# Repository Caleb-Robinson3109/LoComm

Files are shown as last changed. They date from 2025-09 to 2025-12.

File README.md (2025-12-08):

# LoComm Devices: Secure P2P Communication
*LoComm Devices are ESP32s with a LoRa module. The devices provides a low power solution for the secure transmission of data over 915 MHz radio. Providing long range but lower bandwidth. With the use of the computer API applications can be built to utilize the device’s functionality*

## Team Members
Ethan Kleine - ejkmvp@umsystem.edu \
Abraham Yirga - aayfn7@umsystem.edu \
Caleb Robinson - cmrd2d@umsystem.edu \
Kush Solanki - kysp2d@umsystem.edu \
Shaun Wolfe - swgw8@umsystem.edu \
Arjun Kirubakaran - apkccy@umsystem.edu

## Problem Statement
In areas without reliable internet or cellular infrastructure, people, and IoT devices may face serious communication barriers. In these areas secure communication is still required, protecting sensitive or proprietary information. A low cost device that provides secure communication, where wireless infrastructure is not available is a need for these situations.

## Solution
This project provides a secure peer to peer communication system that operates without internet or cellular infrastructure. Using LoRa enabled ESP32 devices and a desktop application, users can exchange secure text messages, giving people a way to communicate privately and consistently. 

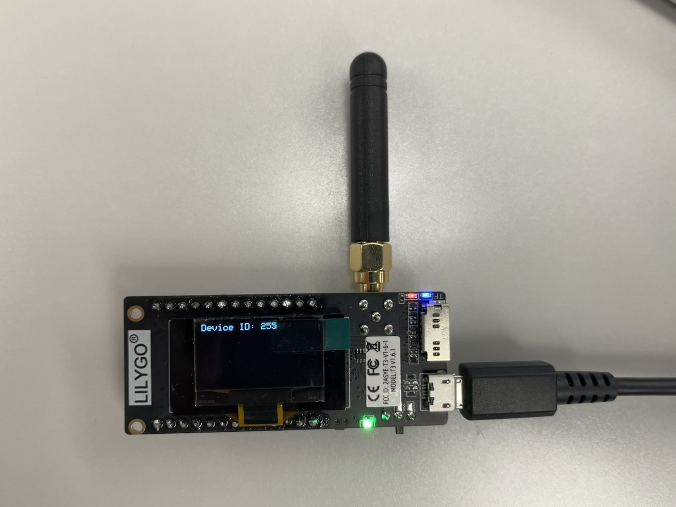
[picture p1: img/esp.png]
ESP32 with LoRa Module


LILYGO LoRa32 915Mhz ESP32 Development Board OLED 0.96 Inch SD Card BLE WiFi \
Cost: $30.00

## Device Security
The LoComm device is designed to maintain security in any remote environment regardless of available infrastructure.
- **Authentication** - Access to each LoComm device requires a user-set password.
- **Authorization** - The user-set password is required to determine the shared symmetric key used for encryption. 
- **Confidentiality** - Shared secret key encryption via AES-GCM
- **Integrity** - Shared secret key encryption via AES-GCM. Replay attacks are avoided with timestamped messages.
- **Reliability** - Message ACKs are used to verify messages were received, and messages are segmented to aid transmission success rate.

## Message Format
| Feild Name | Field Size |
| --- | :---: |
| Start Byte | 1 Byte |
| 0 | 1 Byte |
| Sender ID (Encrypted) | 1 Byte |
| Receiver ID (Encrypted) | 1 Byte |
| Message Number (Encrypted) | 2 Bytes |
| Sequence Number (Encrypted) | 1 Byte |
| Sequence Count (Encrypted) | 1 Byte |
| Timestamp (Encrypted) | 4 Bytes |
| DATA (Encrypted) | N Bytes |
| Encryption Overhead (Encrypted) | 20 Bytes |
| CRC | 2 Bytes |
| End Byte | 1 Byte |

## Device API
The API consists of many functions to communicate with the device in Python.  These API functions can facilitate the connection form application to device, transmission of messages, pairing key handling, etc. 

## Desktop App
The desktop application is designed to be interactive and support secure peer to peer messaging over short range connections.

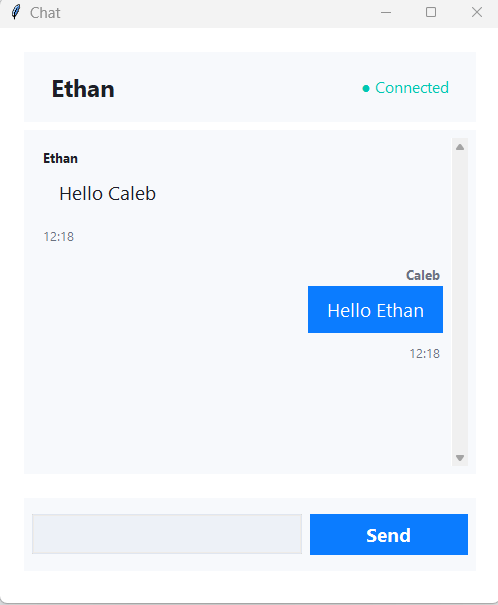
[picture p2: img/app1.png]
Desktop App Chat Page

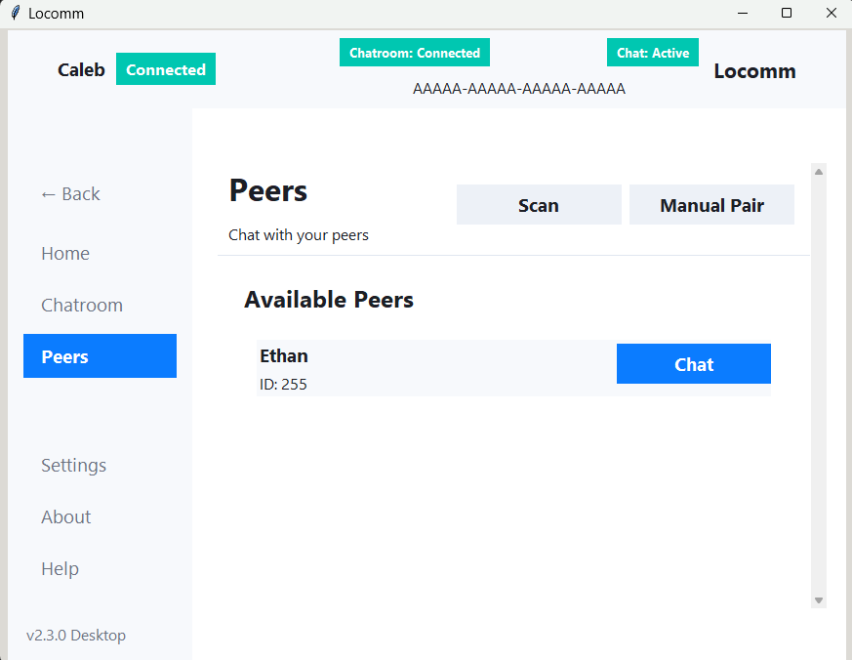
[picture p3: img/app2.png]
Desktop App Peers Page


## Performance
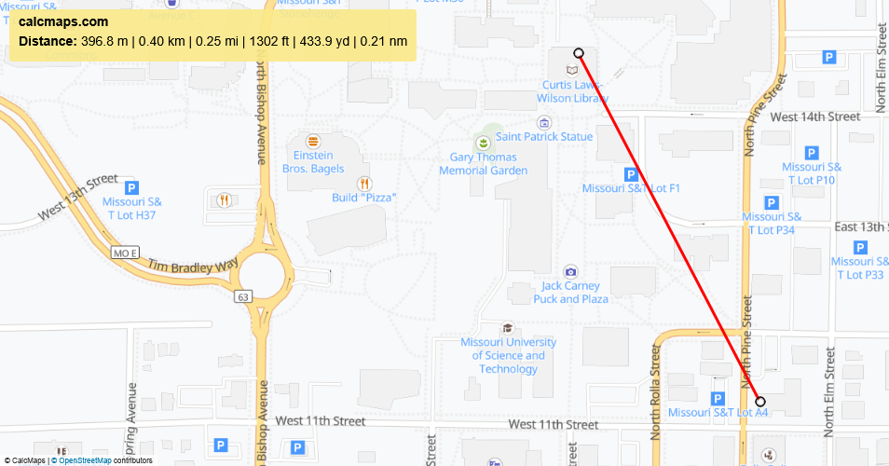
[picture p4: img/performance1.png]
Performance Without Direct Line of Sight

Indoor to outdoor communication at a distance of 0.25 miles messages messages sent without issues. Indoor to indoor communication at 0.24 miles, the devices were not able to receive messages from each other

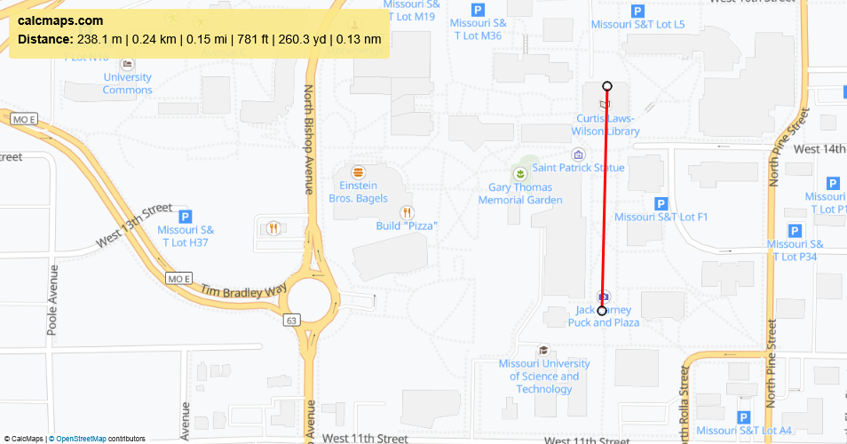
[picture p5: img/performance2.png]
Performance With Direct Line of Sight

A test of 30 messages sent at a distance of 0.15 miles from outdoor to indoor resulted in zero dropped messages. There was 1 out of order message: 1, …, 27, 29, 30, 28.

## Conclusion
The LoComm Device works well in an outdoor environments. At shorter ranges, it can handle large obstacles blocking line-of-sight between devices. This device would work in a smart agriculture scenario, where there are large fields, and power consumption is a concern. Other applications of this device include in industrial warehouses, where low cost wireless communication is crucial, and the defense industry where a secure form of data transfer is critical.

## Future Work
Continued work on this project would introduce features including: frequency hopping to prevent jamming attacks, improved antennas for better bandwidth, in-order message delivery enforcement, to prevent out of order messages, and group ACKs for broadcasts.

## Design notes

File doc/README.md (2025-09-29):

# Docs

Keyboard -> App -> Device -> Device -> USB2SercialComm -> App

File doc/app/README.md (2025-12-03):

# LoComm Desktop App

This desktop UI wraps the LoComm device API for pairing, messaging, and device setup.

## Quick Start
- Install Python 3.11+ and required packages (see project root instructions).
- From the repo root run: `python -m src.app.app`.
- The window opens centered in a compact “Login” layout; it expands after login.

## Authentication Flow
- **Register (Set Password):** On the login page click `Register` to open the modal. Enter and confirm a password (3–32 chars). The app sends `reset_passoword(...)` to the device. On success the password field is prefilled and validation runs.
- **Validate Password:** Enter the device password and click `Validate`. The app calls `enter_password(...)`. When accepted, the “Preferred Name” field unlocks and you can proceed.
- **Login:** After validation, enter a display name (sent to the device via `store_name_on_device(...)`) and click `Login` to enter the main shell.

## Main Shell
- **Home:** Landing view after login with device status and quick actions.
- **Pair/Chatroom:** Access pairing modal when needed; chat features are currently disabled in UI but transport/session remain active.
- **Theme Toggle:** Switch between light/dark; the app recreates the main frame to apply styles.

## Session & Transport
- The app bootstraps `AppController` for business logic and connects to the device on launch (deviceless mode can be toggled in code for testing).
- On logout or window close the controller stops the transport session and clears UI state.

## Troubleshooting
- Password rejected: ensure length 3–32 and retry Validate; use Register to reset if needed.
- Device not detected: reconnect hardware, then restart the app to re-init transport.
- UI unresponsive after modal: close secondary windows first (Register modal grabs focus).

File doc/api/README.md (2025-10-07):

# Device API

This API provides a set of functions for managing connections, authentication, and communication with an ESP-based device.

## Table of Contents
- [Connection Management](#connection-management)
- [Authentication](#authentication)
- [Messaging](#messaging)
- [Pairing](#pairing)

---

## Connection Management

### `connect_to_device() -> bool`
Connects to the device.

**Returns:**  
- `True` if the connection is successful.  
- `False` otherwise.

---

### `disconnect_from_device() -> bool`
Disconnects from the currently connected device.

**Returns:**  
- `True` if disconnection is successful.  
- `False` otherwise.

---

## Authentication

### `enter_password(password: str) -> bool`
Verifies the provided password against the one stored on the ESP.

**Parameters:**  
- `password`: The password string to authenticate with.

**Returns:**  
- `True` if the password is correct.  
- `False` otherwise.

---

### `set_password(old: str, new: str) -> bool`
Changes the device password.

**Parameters:**  
- `old`: The current password.  
- `new`: The new password to be set.

**Returns:**  
- `True` if the password is successfully updated.  
- `False` otherwise.

---

### `reset_password(password: str) -> bool`
**Warning:** This action will delete all device-to-device communication keys on the ESP.  
Use this only if you cannot remember the current password.

**Parameters:**  
- `password`: The reset password authorization string.

**Returns:**  
- `True` if the reset is successful.  
- `False` otherwise.

---

## Messaging

### `send_message(name: str, message: str) -> bool`
Sends a message to the ESP to be broadcasted.

**Parameters:**  
- `name`: The sender’s name or device identifier.  
- `message`: The message content to send.

**Returns:**  
- `True` if the message was sent successfully.  
- `False` otherwise.

---

### `receive_message() -> tuple[str, str]`
Receives messages from the ESP.

**Returns:**  
A tuple containing:
- `name`: The sender’s name or device identifier.  
- `message`: The message content received.

---

## Pairing

### `pair_devices() -> bool`
Initiates device pairing mode.

**Returns:**  
- `True` if pairing is successful.  
- `False` otherwise.

---

### `stop_pair() -> bool`
Cancels the ongoing pairing process.

**Returns:**  
- `True` if pairing was successfully stopped.  
- `False` otherwise.

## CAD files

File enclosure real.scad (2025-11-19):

//  SELECT PART  
PART = "both"; // ["bottom","top","both"]

//  MAIN PCB DIMENSIONS
board_len = 65.53;         // x
board_wid = 30;         // Y
board_thk = 1.6;           // PCB thickness

// Tallest components (above PCB top / below PCB bottom)
comp_bottom = 3.0;
comp_top    = 12.1;        // ≈ 0.54" total - 1.6mm PCB

//  PLASTIC THICKNESSES & CLEARANCES 
wall  = 2.0;
floor = 2.0;
lid   = 2.0;

clear_xy = 0.6;            // side clearance
clear_z  = 0.6;            // vertical breathing room

//  USB PORT #1
// NOTE: "short" => long X wall; "long" => short Y wall (the PCB end)
usb_present = true;
usb_is_typeC = true;       // set false if you switch to USB-A sizes
usb_side = "long";
usb_offset_from_left = 21;
usb_wall_clearance   = 0.40;

// USB PORT #2 (Micro-USB)
usb2_present = true;
usb2_is_typeC = false;     // micro
usb2_side = "long";
usb2_offset_from_left = 5;
usb2_wall_clearance   = 0.40;

// USB shell sizes (re-measure)
usbC_w=8.9;  usbC_h=3.3;  usbC_depth=6.5;
micro_w=7.6; micro_h=2.9; micro_depth=6.0;

//  SMA ANTENNA 
antenna_bulkhead = true;
sma_on_short_side = true;        // true => use a LONG wall (X)
sma_long_wall_face = "far";      // ["near","far"]
sma_offset_from_left = 12;
sma_hole_d = 7.8;
sma_flat_clear = 11.0;

//  VENTING 
side_vents = false;
lid_vents  = true;
vent_slot  = [1.2, 12];
vent_pitch = 4.0;

//  LID LIP (filled lid with overlap) 
lid_rabbet_depth = 1.0;
lid_rabbet_clear = 0.25;

//  STANDOFFS / MOUNTING 
standoff_h=5.0;
standoff_d=5.0;
insert_hole_d=3.6;         // for M2.5 heat-set insert
through_hole_d=2.6;        // M2.5 clearance

hole_inset=3.0;
mount_holes=[
  [hole_inset,            hole_inset],
  [board_len-hole_inset,  hole_inset],
  [board_len-hole_inset,  board_wid-hole_inset],
  [hole_inset,            board_wid-hole_inset]
];

//  DERIVED DIMENSIONS 
inner_len = board_len + 2*clear_xy;
inner_wid = board_wid + 2*clear_xy;
body_len  = inner_len + 2*wall;
body_wid  = inner_wid + 2*wall;

base_cavity = floor + standoff_h + board_thk + comp_top + clear_z;
lid_inner   = lid;
body_ht     = base_cavity + lid_inner;

//  Toggles (preview helpers) 
show_pcb_preview = true;   // set false to hide green board
show_usb_markers = false;  // set true to see small spheres at USB centers

// 
// Helpers
// 
module horiz_slot(len,wid,thk){ cube([len,wid,thk],center=true); }
module pcb_outline(){ cube([board_len,board_wid,board_thk],center=false); }

module standoff(pos,through=false){
  translate([wall+clear_xy+pos[0], wall+clear_xy+pos[1], floor])
  difference(){
    cylinder(h=standoff_h,d=standoff_d,$fn=40);
    translate([0,0,-0.1])
      cylinder(h=standoff_h+0.2, d=(through?through_hole_d:insert_hole_d), $fn=28);
  }
}

//  Rounded-rectangle helpers (for nice USB openings) 
module _roundrect_2d(w,h,r){
  r = min(r, w/2, h/2);
  offset(r=r) square([w-2*r, h-2*r], center=true);
}
module rr_y(w,h,thk,r){ // through Y (long X wall)
  rotate([90,0,0]) linear_extrude(height=thk, center=true) _roundrect_2d(w,h,r);
}
module rr_x(w,h,thk,r){ // through X (short Y wall)
  rotate([0,90,0]) linear_extrude(height=thk, center=true) _roundrect_2d(w,h,r);
}
micro_corner_r = 0.6;
usbC_corner_r  = 1.2;


// USB CUTOUTS (two ports) — rounded

module usb_cutout_port(is_typeC, side, offset_from_left, wall_clear){
  usb_w   = is_typeC ? usbC_w : micro_w;
  usb_h   = is_typeC ? usbC_h : micro_h;
  depth   = is_typeC ? usbC_depth : micro_depth;
  slack_w = usb_w + 2*wall_clear;
  slack_h = usb_h + 2*wall_clear;
  cr      = is_typeC ? usbC_corner_r : micro_corner_r;
  flare   = 0.6; // inside relief

  if (side=="short"){ // long X wall => extrude along Y
    x = offset_from_left + wall;
    z = floor + standoff_h + board_thk/2;
    translate([x,-0.01,z]) rr_y(slack_w,slack_h,wall+0.02,cr);
    translate([x, wall + depth/2, z]) rr_y(slack_w+flare,slack_h+flare,depth+2,cr+0.3);
  } else {            // short Y wall => extrude along X (swap w,h so width is horizontal)
    y = offset_from_left + wall;
    z = floor + standoff_h + board_thk/2;
    translate([-0.01,y,z]) rr_x(slack_h,slack_w,wall+0.02,cr);
    translate([wall + depth/2, y, z]) rr_x(slack_h+flare,slack_w+flare,depth+2,cr+0.3);
  }
}

module usb_cutouts(){
  if (usb_present)
    usb_cutout_port(usb_is_typeC, usb_side, usb_offset_from_left, usb_wall_clearance);
  if (usb2_present)
    usb_cutout_port(usb2_is_typeC, usb2_side, usb2_offset_from_left, usb2_wall_clearance);
}

// Optional USB center markers
module _usb_center_markers(){
  z = floor + standoff_h + board_thk/2;
  if (usb_present){
    if (usb_side=="short") translate([usb_offset_from_left+wall, wall/2, z]) color("red") sphere(d=1.8);
    else                   translate([wall/2, usb_offset_from_left+wall, z]) color("red") sphere(d=1.8);
  }
  if (usb2_present){
    if (usb2_side=="short") translate([usb2_offset_from_left+wall, wall/2, z]) color("lime") sphere(d=1.8);
    else                    translate([wall/2, usb2_offset_from_left+wall, z]) color("lime") sphere(d=1.8);
  }
}
if (show_usb_markers) %_usb_center_markers();


// SMA HOLE

module sma_hole(){
  if (antenna_bulkhead){
    if (sma_on_short_side){   // LONG wall (X)
      x = sma_offset_from_left + wall;
      z = floor + standoff_h + board_thk + comp_top/2;
      y_hole   = (sma_long_wall_face=="near") ? -0.01            : (body_wid + 0.01);
      y_recess = (sma_long_wall_face=="near") ?  wall/2          : (body_wid - wall/2);
      translate([x, y_hole, z]) rotate([90,0,0]) cylinder(h=wall+0.02, d=sma_hole_d, $fn=40);
      translate([x, y_recess, z]) rotate([90,0,0]) cylinder(h=1.6, d=sma_flat_clear, $fn=6);
    } else {                  // SHORT wall (Y)
      x = body_len/2;
      y = sma_offset_from_left + wall;
      z = floor + standoff_h + board_thk + comp_top/2;
      translate([-0.01,y,z]) rotate([0,90,0]) cylinder(h=wall+0.02, d=sma_hole_d, $fn=40);
      translate([wall/2, y, z]) rotate([0,90,0]) cylinder(h=1.6, d=sma_flat_clear, $fn=6);
    }
  }
}


// Side vents (slots)

module vent_slots_on_wall(short_side=true){
  len    = short_side ? body_len : body_wid;
  usable = len - 20;
  count  = max(0, floor(usable/vent_pitch));
  for(i=[0:count-1]){
    pos = 10 + (i+0.5)/count * usable;
    if(short_side){
      translate([pos,-0.01, body_ht/2]) rotate([90,0,0]) horiz_slot(vent_slot[1], vent_slot[0], wall+0.02);
    } else {
      translate([-0.01,pos, body_ht/2]) rotate([0,90,0]) horiz_slot(vent_slot[1], vent_slot[0], wall+0.02);
    }
  }
}


// Lid vents (grid)

module lid_vent_field(){
  if (lid_vents){
    rows = 5;
    cols = max(0, floor((inner_len-20)/vent_pitch));
    for(r=[0:rows-1]) for(c=[0:cols-1]){
      x = wall+10+c*vent_pitch;
      y = wall + inner_wid/2 - (rows/2 - 0.5)*vent_pitch + r*vent_pitch;
      z = body_ht - lid/2;
      translate([x,y,z]) cube([vent_slot[1], vent_slot[0], lid+0.02], center=true);
    }
  }
}


// Bottom shell (floor + walls + bosses)

module bottom_shell(){
  difference(){
    // outer body
    cube([body_len,body_wid,body_ht],center=false);
    // inner cavity
    translate([wall,wall,lid]) cube([inner_len,inner_wid,body_ht-lid],center=false);

    // cutouts
    usb_cutouts();
    if(side_vents){ vent_slots_on_wall(true); vent_slots_on_wall(false); }
    sma_hole();
  }

  // bosses/standoffs under PCB
  for(p=mount_holes) standoff(p,false);

  // PCB preview (won't export)
  if (show_pcb_preview)
    %color([0,1,0,0.15]) translate([wall+clear_xy, wall+clear_xy, floor+standoff_h]) pcb_outline();
}


// Top lid (filled, with shallow overlap lip)

module top_lid(){
  difference(){
    // solid plate
    translate([0,0,body_ht-lid]) cube([body_len,body_wid,lid],center=false);

    // shallow lip recess
    translate([wall - lid_rabbet_clear,
               wall - lid_rabbet_clear,
               body_ht - lid - 0.01])
      cube([inner_len + 2*lid_rabbet_clear,
            inner_wid + 2*lid_rabbet_clear,
            lid_rabbet_depth + 0.02], center=false);

    // screw through-holes
    for(p=mount_holes)
      translate([wall+clear_xy+p[0], wall+clear_xy+p[1], body_ht-lid-0.01])
        cylinder(h=lid+0.02, d=through_hole_d, $fn=28);

    // lid vents
    lid_vent_field();
  }
}


// Render selector

if (PART=="bottom") color("gainsboro") bottom_shell();
else if (PART=="top") color("white") top_lid();
else { color("gainsboro") bottom_shell(); color([1,1,1,0.35]) top_lid(); }

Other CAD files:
FinalDesignEnclosure.scad

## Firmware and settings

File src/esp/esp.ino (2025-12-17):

//Libraries for LoRa
#include "functions.h"

#include "globals.h"

//api functions
#include "apiCode.h"
#include "security_protocol.h"

extern Preferences storage;


//uint8_t deviceIDList[32]; 
bool deviceIDDataChanged = false;

uint8_t lastDeviceMode = IDLE_MODE;
uint32_t nextCADTime = 0;
//Adafruit_SSD1306 display(SCREEN_WIDTH, SCREEN_HEIGHT, &Wire, OLED_RST);

//uint32_t epochAtBoot = 0; //TODO this should be set and required to be set at boot

//Variables for Device ID resolution and maintenance
bool sendDeviceIDResponse = false;
uint32_t lastDeviceIDResponseTime = 0;
uint8_t deviceIDResponseBuffer[10+AES_GCM_OVERHEAD];
bool sendDeviceIDTableResponse = false;
uint32_t lastDeviceIDTableResponseTime = 0;
uint8_t deviceIDTableResponseBuffer[41+AES_GCM_OVERHEAD];
bool sendDeviceIDRequest = false;
uint32_t lastDeviceIDRequest = 0;
uint8_t deviceIDRequestBuffer[10+AES_GCM_OVERHEAD];
bool sendDeviceIDTableRequest = false;
uint32_t lastDeviceIDTableRequestTime = 0;
uint8_t deviceIDTableRequestBuffer[10+AES_GCM_OVERHEAD];


//State tracking variables
bool receiveReady = false;
bool messageDispatched = false;
bool ackDispatched = false;
bool enableLora = false;
CyclicArrayList<uint16_t, 128> previouslySeenIds;
CyclicArrayList<uint16_t, 128> previouslyProcessedIds;

//LoRa RX Related Variables
CyclicArrayList<uint8_t, LORA_RX_BUFFER_SIZE> rxBuffer; //buffer used to store raw data received from LoRa. This is then processed later
uint16_t rxBufferLastSize = 0;
SimpleArraySet<256, 11> rxMessageArray; //used to store information about successfully processed received messages
DefraggingBuffer<2048, 8> rxMessageBuffer; //used to combine received segmented messages into the final full message

//LoRa TX Related Variables
SimpleArraySet<256, 9> txMessageArray; //buffer used to store information about individual packets that should be dispatched
DefraggingBuffer<2048, 8> txMessageBuffer; //used to store the raw data that should be dispatched
CyclicArrayList<uint8_t, LORA_READY_TO_SEND_BUFFER_SIZE> readyToSendBuffer; //Queue for LoRa device. This just contains a length and an address into the txMessageBuffer
CyclicArrayList<uint8_t, LORA_ACK_BUFFER_SIZE> ackToSendBuffer; //Queue for Acks for the LoRa device. This contains raw ACK messages since they are relatively small

//Serial TX Related Variables
//TODO for sake of performance, this should probably be a CyclicArrayList
//SimpleArraySet<SERIAL_READY_TO_SEND_BUFFER_SIZE, 4> serialReadyToSendArray; //Queue for sending data out to serial //(location in the rxMessageBuffer, size)

//Since both the lora code and api code may need access to the lora rx and tx buffers, both need locks
portMUX_TYPE loraRxSpinLock = portMUX_INITIALIZER_UNLOCKED;
bool loraRxLock = false;
portMUX_TYPE loraTxSpinLock = portMUX_INITIALIZER_UNLOCKED;
bool loraTxLock = false;
portMUX_TYPE serialLoraBridgeSpinLock = portMUX_INITIALIZER_UNLOCKED;
bool serialLoraBridgeLock = false;

bool receivedDeviceIDTable = false;

StackType_t apiStack[API_CODE_STACK_SIZE];
StaticTask_t apiStackBuffer;

void setup() {
  pinMode(2, OUTPUT);
  blinky1();

  //initialize variables
  rxBuffer = CyclicArrayList<uint8_t, LORA_RX_BUFFER_SIZE>();
  rxMessageArray = SimpleArraySet<256, 11>();
  rxMessageBuffer = DefraggingBuffer<2048, 8>();
  rxMessageBuffer.init();
  txMessageArray = SimpleArraySet<256, 9>();
  txMessageBuffer = DefraggingBuffer<2048, 8>();
  txMessageBuffer.init();
  readyToSendBuffer = CyclicArrayList<uint8_t, LORA_READY_TO_SEND_BUFFER_SIZE>();
  ackToSendBuffer = CyclicArrayList<uint8_t, LORA_ACK_BUFFER_SIZE>();
  serialReadyToSendArray = SimpleArraySet<SERIAL_READY_TO_SEND_BUFFER_SIZE, 5>();
  previouslySeenIds = CyclicArrayList<uint16_t, 128>();
  previouslyProcessedIds = CyclicArrayList<uint16_t, 128>();

  if (!storage.begin("LoComm", 0)) {
    LError("Failed to start storage instance!");
    HALT();
  }

  //preload address resolution buffers with data that doesnt change
  deviceIDRequestBuffer[0] = START_BYTE;
  deviceIDRequestBuffer[1] = 2;
  deviceIDRequestBuffer[9 + AES_GCM_OVERHEAD] = END_BYTE;
  
  deviceIDResponseBuffer[0] = START_BYTE;
  deviceIDResponseBuffer[1] = 3;
  deviceIDResponseBuffer[9 + AES_GCM_OVERHEAD] = END_BYTE;

  deviceIDTableRequestBuffer[0] = START_BYTE;
  deviceIDTableRequestBuffer[1] = 4;
  deviceIDTableRequestBuffer[9 + AES_GCM_OVERHEAD] = END_BYTE;

  deviceIDTableResponseBuffer[0] = START_BYTE;
  deviceIDTableResponseBuffer[1] = 5;
  deviceIDTableResponseBuffer[40 + AES_GCM_OVERHEAD] = END_BYTE;


  //Initialize Serial Connection to Computer
  Serial.begin(115200);
  Serial1.setPins(26, 25);
  Serial1.begin(115200); //TODO set pins for serial1

  while (!Serial);
  while (!Serial1);

  //Initialize OLED Screen
  delay(1000);
  Wire.begin(OLED_SDA, OLED_SCL);
  if(!display.begin(SSD1306_SWITCHCAPVCC, 0x3C, true, false)) { 
    Serial1.println(F("SSD1306 allocation failed"));
    while(1); // Don't proceed, loop forever
  }
  display.clearDisplay();
  display.setTextColor(SSD1306_WHITE);
  display.setTextSize(1);

  //Initialize LoRa
  SPI.begin(SCK_LORA, MISO_LORA, MOSI_LORA, SS_LORA);
  LoRa.setPins(SS_LORA, RST_LORA, DIO0_LORA);
  if (!LoRa.begin(BAND)) {
    Serial1.println("Starting LoRa failed!");
    display.clearDisplay();
    display.print("Failed to init LoRa");
    display.display();
    while (1);
  }

  //Register Callbacks
  LoRa.onTxDone(onTxDone);
  LoRa.onCadDone(onCadDone);
  LoRa.onReceive(onReceive);

  //Set idle mode
  Debug(Serial1.println("Setup Finished"));
  enterReceiveMode();
  display.clearDisplay();
  display.printf("Device ID: %d\n", deviceID);
  display.display();

  //init security
  sec_init();
  //sec_setInitialPassword("password");

  //initialize api task
  delay(1000);
  Serial.println("Booting");
  Serial.flush();
  
  xTaskCreateStaticPinnedToCore(
    apiCode,
    "APICODE",
    API_CODE_STACK_SIZE,
    (void*) 1,
    0,
    apiStack,
    &apiStackBuffer,
    0
  );

  //init the password and keys
  init_password();
}

void loop() {
  static uint8_t tempDeviceMode = 255; //debug variable used to print changes in device mode
  static bool shouldScanRxBuffer = false; //flag that gets set when the rxBuffer should be scanned through (ie. when data is added)

  //Debug: If a device mode change was detected log it to serial if we are in debug mode
  if (lastDeviceMode != tempDeviceMode) {
    Debug(Serial1.printf("Device Mode change detected! New device mode is %d\n", lastDeviceMode));
    tempDeviceMode = lastDeviceMode;
  }

  //----------------------------------------------------- MISC State Behavior -------------------------------------------------
  if (lastDeviceMode == CAD_FAILED) { //if CAD detected a signal, then just go back to RX mode until CAD is ready to try again
    LoRa.receive();
    lastDeviceMode = RX_MODE;
    LError("CAD detected a signal! trying again later");
  }
  static bool startedDeviceIDAcquire = false;
  static bool initializedDeviceRouting = false;
  //Some debug information for logging in 
  static uint32_t lastDebugPrintTime = millis();
  static uint8_t printTimeCount = 0;
  if (millis() - lastDebugPrintTime > 5000) {
    lastDebugPrintTime = millis();
    Debug(Serial1.printf("\nPaired Status: %d\nLogged In Status: %d\n", sec_isPaired(), sec_isLoggedIn()));
    Debug(Serial1.printf("Current Device ID: %d\n", deviceID));
    Debug(Serial1.printf("initializedDeviceRouting: %d\n", initializedDeviceRouting));
    Debug(Serial1.printf("startedDeviceIDAcquire: %d\n", startedDeviceIDAcquire));
    Debug(Serial1.printf("receivedDeviceIDTable: %d\n", receivedDeviceIDTable));
    printTimeCount++;
    if (printTimeCount > 6) {
      printTimeCount = 0;
      LDebug("Dumping Device ID Table contents:");
      for(int i = 0; i < 32; i++) {
        Debug(Serial1.printf("%d ", deviceIDList[i]));
      }
      Debug(Serial1.printf("\n"));

    }
  } 

  enableLora = sec_isPaired() && sec_isLoggedIn() && epochAtBoot != 0;
  static bool lastLoraEnableStatus = !enableLora;
  if (lastLoraEnableStatus != enableLora) {
    LDebug("Lora Enable status has changed!");
    switch (lastLoraEnableStatus) {
      case true: //actually false since we are checking the previous state
        LDebug("Lora has been disabled, putting into sleep mode");
        LoRa.sleep();
        lastDeviceMode = SLEEP_MODE;
        receiveReady = false;
        shouldScanRxBuffer = false;
        {
          ScopeLock(loraRxSpinLock, loraRxLock);
          rxMessageArray.clearAll();
          rxMessageBuffer.clear();
        }
        {
          ScopeLock(loraTxSpinLock, loraTxLock);
          txMessageArray.clearAll();
          txMessageBuffer.clear();
        }
        rxBuffer.clearBuffer();
        readyToSendBuffer.clearBuffer();
        ackToSendBuffer.clearBuffer();
        previouslySeenIds.clearBuffer();
        previouslyProcessedIds.clearBuffer();
        serialReadyToSendArray.clearAll();
      break;
      case false: //actually true since we are checking the opposite case
        LDebug("Lora has been enabled");
        rxBuffer.clearBuffer();
        LoRa.receive();
        lastDeviceMode = RX_MODE;
    }
    lastLoraEnableStatus = enableLora;
  }


  //-------------------------------------------------------Device ID management ----------------------------------------------------

  static uint32_t lastPrintedDeviceIDTime = millis();
  if (millis() - lastPrintedDeviceIDTime > 5000) {
    lastPrintedDeviceIDTime = millis();
    display.setCursor(0,0);
    display.clearDisplay();
    display.printf("Device ID: %d\n", deviceID);
    display.display();
  }
  

  static uint32_t deviceIDAcquireStartTime = millis();
  //if we have logged in, then pull the device ID and table from memory. if they arent stored, then just put 255 in for the device ID and a blank table in
  if (sec_isLoggedIn() && sec_isPaired() && epochAtBoot != 0 && !sec_is_key_changed()) {
    //If we have not initialized the device routing yet, then initialize it
    if (!initializedDeviceRouting) {
      LDebug("Logged in and paired! initializing device routing variables");
      initializedDeviceRouting = true;
      initializeDeviceRouting();
    }

    //If the deviceIDchanged flag is set, then the table has changed, or the device ID has changed. Either way, trigger a full rewrite to EEPROM
    if (deviceIDDataChanged) {
      LDebug("Device ID data has changed!, attempting to write data to EEPROM");
      storeDeviceIDData(false);
    }

    //if our device ID is currently 255, then we are in searching mode, 
    if (deviceID == 255) {
      if (!startedDeviceIDAcquire) {
        LDebug("Device ID is set to 255, trying to acquire a device ID");
        startedDeviceIDAcquire = true;
        receivedDeviceIDTable = false; 
        deviceIDAcquireStartTime = millis();
      }
      sendDeviceIDQueryMessages();
      if (receivedDeviceIDTable || millis() - deviceIDAcquireStartTime > 10000) {
        LDebug("Device ID table has been received, or we've hit the 10 second timeout, attempting to acquire a device ID");
        chooseOpenDeviceID();
        LDebug("Acquired Device ID!");
        //now that an id has been chosen, send out ID, and force update our table
        storeDeviceIDData(true);
        sendDeviceIDResponseFunc();
      }
    } else {
      startedDeviceIDAcquire = false;
    }

    //Every 60 or so seconds, send out an additional device ID request
    static uint32_t lastRandomDeviceIDRequestSendTime = millis();
    if (millis() - lastRandomDeviceIDRequestSendTime > 60000) {
      LDebug("60 seconds elapsed: sending additional random device ID request");
      sendDeviceIDRequestFunc();
      lastRandomDeviceIDRequestSendTime = millis();
    } 


  } else if (sec_isLoggedIn()) {
    //logged in, but unpaired, so clear the device routing completely
    if (initializedDeviceRouting) {
      LDebug("User is logged in but is not paired, clearing local routing data");
      resetDeviceRouting();
      initializedDeviceRouting = false;
    }
  } else {
    //LDebug("One of the chatting conditions was met, setting the device ID to 255 and uninitializating device routing")
    //we are not logged in anymore, so just clear the local variabes, dont need to worry about deleting the eeprom
    deviceID = 255;
    initializedDeviceRouting = false;
  }
   


  
  

  //------------------------------------------------------RX Interrupt flag handling ------------------------------------------------
  if (receiveReady) { //receiveReady indicates the LoRa has read data, and data is now available. This flag gets set by the RX interrupt
    LDebug("Handling receive flag");
    int size = LoRa.available();
    receiveReady = false;
    
    //Dump the data into a temporary buffer
    uint8_t tempBuf[256];
    LoRa.readBytes(tempBuf, min(256, size));

    //If there is still data in the buffer, then something isn't right
    //because the max LoRa message size is 256 bytes
    if (LoRa.available()) {
      LError("Received more than 256 bytes in LoRa buffer, which was unexpected!");
      HALT();
    }

    //try to add data the received data to our rxBuffer for later processing
    if (rxBuffer.pushBack(tempBuf, size)) {
      LDebug("Added data to LoRa rx buffer");
      Debug(Serial1.printf("First Byte of Data: %d\n", tempBuf[0]));
      Debug(Serial1.printf("Second Byte of Data: %d\n", tempBuf[1]));
      //Data was successfully added, so set the shouldScanRxBuffer condition
      shouldScanRxBuffer = true;
    } else {
      LWarn("Rx Buffer is currently full, not adding data");
    }

    //NOTE - After the rx is completed, what mode is the lora in? We assume it remains in RX mode for now, so no mode change is necessary
  }

  // -------------------------------------------------- Receive Loop Behavior ---------------------------------------------
  if (shouldScanRxBuffer) { //this gets set to true when data gets added to rxBuffer, or if theres still potentially a message in rxBuffer after a scan
    //First, we will scan for start bytes. If we find any, we will then scan from the start byte to j in range(rxBufferLastSize, actual buffer size)
    //If we find a valid message, we will clear any data from the buffer before the valid message.
    /*PseudoCode
      for each start byte:
        if there is a valid message with the end byte in (rxBufferLastSize, actual buffer size)
          process messages
          clear all data in the buffer up to the end of the message
          update rxBufferLastSize to the end of the messages
        if no valid message is found and we've scanned 256 bytes, then clear everything up to and including the start byte
      if no message was ever found, then update rxBufferLastSizeto the end of the data
    

    */
    shouldScanRxBuffer = false;
    bool messageFound = false;
    for (int startByteLocation = 0; startByteLocation < rxBuffer.size(); startByteLocation++) {
      
      if (rxBuffer[startByteLocation] == START_BYTE) {
        //start byte found, scan from rxBufferLastSize to rxBuffer.size() for the end byte
        if (rxBufferLastSize > rxBuffer.size()) {
          LDebug("RXBufferLastSize was not properly updated, and it is now larger than rxBuffer!");
          HALT();
        }
        for (int endByteLocation = max(startByteLocation+1, (int) (rxBufferLastSize - 1)); endByteLocation < min((int) (startByteLocation + 256), (int) rxBuffer.size()); endByteLocation++) {
          if (rxBuffer[endByteLocation] == END_BYTE) {
            const uint8_t messageSize = endByteLocation - startByteLocation + 1;
            if (messageSize < 8 + AES_GCM_OVERHEAD) continue;
            LDebug("Found End Byte in rxBuffer");
            LDebug("Message Identified...");
            //Debug(dumpArrayToSerial(&(rxBuffer[0]), i+1));

            //First, Calculate the CRC and check if its correct 
            uint32_t crc = (~esp_rom_crc32_le((uint32_t)~(0xffffffff), (const uint8_t*)(&(rxBuffer[startByteLocation+1])), messageSize - 4))^0xffffffff;
            uint16_t msgCrc = (rxBuffer[endByteLocation-2] << 8) + rxBuffer[endByteLocation-1]; 
            if ((crc & 0xFFFF) != msgCrc) {
              LDebug("Received RX message does not have matching CRC, skipping");
              continue;
            } 

            //check if that packet type is invalid
            const uint8_t packetType = rxBuffer[startByteLocation+1];
            if (packetType > 5) {
              LDebug("Received RX message does not have proper type byte, skipping");
              continue;
            }

            //Since CRC passed, its time to decrypt the message, so lets decrypt it into a temp buffer
            uint8_t tempBuf[256];
            size_t plaintextLen;
            if (!decryptD2DMessage(&(rxBuffer[startByteLocation+2]), messageSize-5, &(tempBuf[0]), 256, &plaintextLen)) {
              LDebug("Decryption Failed, assuming message has been tampered with since CRC still passed");
              //TODO tamper detection OR different key detection
              continue;
            }

            //Verify the plaintextLen is what is expected
            if (plaintextLen != messageSize - 5 - AES_GCM_OVERHEAD) {
              LError("Received plaintext message from rx is unexpected size!");
              HALT();
            }

            //Now, the message should be fully contained in tempBuf with length plainTextLen, which excludes the start/stop bytes, the message type, the encryption overhead, and the CRC
            //since we got this far, we can reasonably assume the message is valid, so we can remove it from the buffer
            messageFound = true;
            rxBuffer.dropFront(endByteLocation+1);
            rxBufferLastSize = 0;
            shouldScanRxBuffer = true; //there could be another message to find, go look again

            //Check if we should filter out the message based on message type and potential receiver field
            bool broadcast = false; //used to indicate if a data message is intended for broadcast, so no ack should be sent out
            bool breakout = false;
            switch (packetType) {
              case 0:
                if (tempBuf[1] == 255) {
                  broadcast = true;
                } else if (tempBuf[1] != deviceID) {
                  LDebug("Received RX Data message is not intended for sender, skipping");
                  //log the message ID
                  const uint16_t messageNumber = (tempBuf[2] << 8) + tempBuf[3]; 
                  previouslySeenIds.pushBack(&messageNumber, 1);
                  if (previouslySeenIds.size() >= 128) {
                    previouslySeenIds.dropFront(1);
                  }

                  //log the deviceID of the sender
                  addDeviceIDToTable(tempBuf[0]);
                  breakout = true; //the message was intended for this device, so indicate we should break out
                }
                break;
              case 1:
                if (tempBuf[1] != deviceID) {
                  LDebug("Received RX Ack message is not intended for sender, skipping");
                  breakout = true;
                }
                break;
              case 2: //device ID scan is a broadcast message, so no receiver field is present
                break;
              case 3: //device ID scan response is also a broadcast message, so no receiver field is present
                break;
              case 4: //device ID full table request DOES have a receiver field, so filter on it
                if (tempBuf[0] != deviceID) {
                  LDebug("Received Device ID Table request is not intended for sender, skipping");
                  breakout = true;
                }
              case 5: //device ID full table response is also a broadcast message, so no receiver field is present
                break;
            }
            if (breakout) break;

            //check if the message was intended to be sent in the last 20 seconds based on the timestamp
            //Since timestamp is dependant on message type, use a switch statement to acquire it
            uint32_t timestamp;
            switch (packetType) {
              case 0:
                //data packet
                timestamp = (tempBuf[6] << 24) + (tempBuf[7] << 16) + (tempBuf[8] << 8) + tempBuf[9];
              break;
              case 1:
                //ack packet
                timestamp = (tempBuf[5] << 24) + (tempBuf[6] << 16) + (tempBuf[7] << 8) + tempBuf[8];
              break;
              case 2: //device id request packet
              case 3: //device id response packet
              case 4: //device id table request packet
                timestamp = (tempBuf[1] << 24) + (tempBuf[2] << 16) + (tempBuf[3] << 8) + tempBuf[4];
              break;
              case 5: //device id table response packet
                timestamp = (tempBuf[0] << 24) + (tempBuf[1] << 16) + (tempBuf[2] << 8) + tempBuf[3];
              break;
            }
            const uint32_t currentTime = (millis() / 1000) + epochAtBoot;
            if (currentTime + 5 < timestamp) { //5 is added for a bit of leeway
              LWarn("Received RX Message is from the future! someone likely has invalid time configuration");
              break; 
            }
            if (currentTime > timestamp && currentTime - timestamp > 60) {
              LWarn("received RX Message is very old, possible replay attack attempt");
              Debug(Serial1.printf("current time: %ld\ntime indicated by message: %ld\n", (millis() / 1000) + epochAtBoot, timestamp));
              //TODO logic to log replay attack attempt
              break; 
            }
            
            //Now that checks have passed, we can attempt to process the message. First, lets see what type of message it is
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

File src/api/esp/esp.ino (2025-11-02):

#include "LoCommAPI.h"
#include "LoCommLib.h"
#include "LoCommBuildPacket.h"

#include <Arduino.h>
#include <Wire.h>
#include <LiquidCrystal_I2C.h>

void setup() {
  //blink led
  pinMode(2, OUTPUT);
  
  //set up serial
  Serial.begin(9600);
  delay(1000);
  blinky(2);

  Wire.begin(21, 22);
  lcd.begin();
  lcd.backlight();
  lcd.setCursor(0,0);
  lcd.print("LoComm");

  init_password();
  //debug_simulate_device_in_packet();
}

void loop() {
  //there is a message from the device and the next 2 if statmetns handle that
  if(message_from_device_flag){
    lcd.clear();
    lcd.setCursor(0,0);
    lcd.print("message_from_\ndevice_flag");
    delay(2000);
    handle_message_from_device();
  }

  //there is a message from the device and the subsaquent funcs check and handle that
  recive_packet_from_computer();
  if(message_from_computer_flag){
    handle_message_from_computer();
  }
  if(message_to_device_flag){
    handle_message_to_device();
  }
  if(message_to_computer_flag){
    handle_message_to_computer();
  }
}

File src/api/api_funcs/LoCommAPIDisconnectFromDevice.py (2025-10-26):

import serial
import random
import struct #creation of the packet
import binascii #crc-16 (crc_hqx)
from api_funcs.LoCommContext import LoCommContext
from api_funcs.LoCommDebugPacket import print_packet_debug

def build_DCON_packet(tag: int) -> bytes:
    start_bytes: int = 0x1234
    packet_size: int = 16
    message_type: bytes = b"DCON"

    #compute the payload to calc the crc
    payload: bytes = struct.pack(">H", packet_size) + message_type + struct.pack(">I", tag)
    crc: int = binascii.crc_hqx(payload, 0) 

    end_bytes: int = 0x5678

    packet: bytes = struct.pack(">HH4sIHH", start_bytes, packet_size, message_type, tag, crc, end_bytes)
    return packet

def check_DCAK_packet(packet: bytes, tag: int) -> bool:
    start_bytes: int
    packet_size: int
    message_type: bytes
    ret_tag: int
    crc: int
    end_bytes: int

    start_bytes, packet_size, message_type, ret_tag, crc, end_bytes = struct.unpack(">HH4sIHH", packet)


    payload: bytes = struct.pack(">H", packet_size) + message_type + struct.pack(">I", ret_tag)
    crc_check: int = binascii.crc_hqx(payload, 0)

    #do checks on the package
    if(start_bytes != 0x1234):
        print(f"DCAK start bytes fail - 0x1234, {start_bytes}")
        return False
    
    if(packet_size != 16):
        print(f"DCAK packet size fail - 16, {packet_size}")
        return False
    
    if(message_type != b"DCAK"):
        print(f"DCAK message type fail - DCAK, {message_type}")
        return False
    
    if(ret_tag != tag):
        print(f"DCAK tag mismatch fail - {tag}, {ret_tag}")
        return False
    
    if(crc != crc_check):
        print(f"DCAK crc fail - {crc}, {crc_check}")
        return False
    
    if(end_bytes != 0x5678):
        print(f"DCAK end bytes fail - 0x5678, {end_bytes}")
        return False
    
    return True


def locomm_api_disconnect_from_device(ser: serial.Serial, context: LoCommContext) -> bool:
    if ser == None:
        print(f"no serial connecton to close")
        return False

    try:
        #tell device to delete password on the device
        tag: int = random.randint(0, 0xFFFFFFFF)
        packet: bytes = build_DCON_packet(tag)
        print_packet_debug(packet, True)        
        ser.write(packet)
        ser.flush()

        #wait for responce
        while (not context.DCAK_flag):
            pass

        print_packet_debug(context.packet, False)
        okay: bool = check_DCAK_packet(context.packet, tag)
        
        """
        tries: int = 9

        while(not okay and tries < 10):
            okay = send_recv_packet(ser, packet, tag)
            print(f"try {tries + 1}")
            tries = tries + 1

        if(tries == 10 and not okay):
            raise ValueError("tried to send DCON 10 times and failed each time")
        """


    except Exception as e:
        print(f"closing serial connection error - {e}")
        context.DCAK_flag = False
        return False
    
    context.DCAK_flag = False
    return True

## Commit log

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2025-10-14 fixed small errors with conn and cack
    [LoCommAPI.cpp, LoCommAPIConnectToDevice.py, esp.ino]
2025-10-17 fixed a lot of bugs in the code
    [esp.ino]
2025-10-20 fiexed DCON bug, started on SEND
    [LoCommAPI.cpp, LoCommAPI.py, LoCommAPIDisconnectFromDevice.py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]
2025-10-20 added more logging to try to debug issues
    [esp.ino]
2025-10-20 fixed password not being accepted after 1st run bug
    [LoCommAPI.cpp, LoCommAPIConnectToDevice.py, LoCommAPIDisconnectFromDevice.py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]
2025-10-20 fixed messages still being resent after receiving an ACK
    [esp.ino]
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2025-10-26 some better debug packet messades and start on handle message from device
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2025-10-29 increased message number size to 2 bytes to reduce collisions, added timestamps to packet headers, and added empty functions for implementing AES-GCM on a per packet basis
    [esp.ino, functions.cpp]
2025-11-02 improved message number collision tracking and improved buffer search to be complete
    [esp.ino]
2025-11-02 added locks to tx and rx buffers in preparation for running serial code on a separate thread, and added better state management for completely enabling/disabling lora behavior
2025-11-02 small bug fix regarding timestamping and timestamps slightly out of sync
    [esp.ino]
2025-11-02 small fixes to get the apiCode task running
    [esp.ino]
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2025-11-05 feat: implement security-focused UI redesign with enhanced profile layout and chat controls
    - Remove all export chat functionality for security compliance
    - Add device ID to session model for secure identification
    - Redesign profile layout with three-box header: Paired Devices, Current Chat, My Profile
    - Implement enhanced chat tab with disconnect/clear controls in top-right corner
    - Remove profile picture from My Profile section for cleaner design
    - Fix application startup error (_last_status attribute missing)
    - Add centralized status management and validation utilities
    - Establish service layer architecture with auth_service
    - Optimize user store with caching for better performance
    - Remo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
2025-11-05 fixed issue with stack size and temporarily disabled password setting on boot
    [LoCommLib.cpp, SerialReader.py, esp.ino]
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2025-11-07 Fix header pair button handler
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2025-11-07 Avoid ttk.Frame bg configuration
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2025-11-07 Tighten chat bubble and header layout
2025-11-08 feat: integrate UI store for device status and add connection badge
    Refactor ChatPage to use ui_store for device status snapshots instead of status_manager callbacks, enabling more consistent UI state management. Add a visual connection badge in the header to display "Disconnected" status. Improve mouse wheel scrolling support for Linux by handling Button-4 and Button-5 events. Add a connected check in message sending to prevent actions when disconnected. Remove obsolete device change callback.
2025-11-08 refactor(transport): update LoRa adapter to use shared contracts and registry
    Refactored LoCommTransport to consume new PairingContext and TransportMessage dataclasses, integrate transport registry for profile-based backend resolution, and expose profile metadata properties. This enables backend swapping via config, deterministic status updates, and unified contract surface across backends, completing Phase 1 and Phase 2 integrations for mock data, network simulation, and device discovery.
2025-11-08 refactor: relocate mock services to dedicated directory and enhance device details UI
    - Moved mock_device_service and network_simulator from services/ to mock/ directory
    - Updated import statements and file paths in testing.md and devices_page.py accordingly
    - Added new UI card for selected device details (name, firmware, region, last seen) to improve user visibility
    - Adjusted code placement for better structure, such as moving _refresh_device_table() call
    This refactoring organizes mock-related code into a dedicated mock/ directory for clarity and maintainability, while the UI enhancements provide users with essential device information at a glance.
2025-11-09 feat(app): preserve navigation on theme toggle and enhance connection handling
    - Add route_id parameter to show_main method to support navigation state preservation
    - Modify toggle_theme to save and restore current view when switching themes
    - Import Colors for background configuration in theme toggle
    - Improve pairing context handling in LoCommTransport for better mode detection
    - Enhance error logging and status callbacks in connection process
    - Update ChatPage UI to include a button row for improved layout
2025-11-09 refactor(chat): simplify header layout and update message bubble styles
    - Removed nested frames in chat page header for cleaner structure
    - Repositioned Clear Chat and Disconnect buttons directly in header
    - Adjusted name label and connection badge packing for better alignment
    - Added borderless styling to history canvas
    - Updated message bubble colors and anchors for improved visual consistency
    - Removed mock backend status text in LoRa transport to streamline status display
2025-11-09 feat: enhance mock device variety and chat UI scrolling/layout
    - Updated MockDeviceService.simulate_scan to use dynamic name pools and statuses for more varied synthetic devices, improving UI dynamism.
    - Refactored ChatPage to use global mousewheel helper for smoother scrolling, removed redundant event handlers, and adjusted bubble padding, width, and wraplength for better alignment and readability.
2025-11-09 feat(ui): refactor header layout in chat page and update device page buttons
    - Rearranged chat page header elements for better visual hierarchy: connection badge and name label on left, disconnect and clear buttons on right.
    - Updated devices page button texts ("Scan now" to "Scan", "Scan again" to "Scan") and variants for consistency.
    - Assigned buttons to instance variables (self.scan_btn, self.disconnect_btn) and disabled disconnect button by default to prevent premature actions.
2025-11-09 feat: add mock device and testing page for device interactions
    - Enhanced MockLoCommBackend with specialized responses for Mock device (e.g., greetings, status, ping, echo).
    - Added devices.json file containing mock device metadata and telemetry data.
    - Updated MockDeviceService to prioritize Mock device in device listings.
    - Integrated MockPage into MainFrame routes and created the page class for UI-based testing.
    - Enables protocol testing and simulation of device communications without physical hardware.
2025-11-09 refactor(mock): integrate peer bridge and refine UI sizing
    - Added peer bridge integration in MockLoCommBackend for real-time notifications to peers, improving mock testing fidelity.
    - Disabled heartbeat messages to reduce noise in mock conversations.
    - Simplified device listing in MockDeviceService by removing forced ordering.
    - Adjusted app window sizing to 85% of screen with dynamic minimums for better usability.
    - Tweaked chat bubble padding for improved alignment.
2025-11-09 feat(app): Set default local device name to 'Orion' and enable conditional debug logging
    - Updated default local_device_name from "This Device" to "Orion" for consistent branding
    - Modified notification logic to use "Orion" as fallback device name
    - Wrapped debug print statements in LoRa transport with DEBUG flag checks for cleaner output
    - Adjusted window minsize to match target dimensions for fixed sizing
    - Repositioned UI buttons in chat bar to improve layout (devices_btn to column 8, clear_btn to column 9)
2025-11-09 feat(ui): add dynamic resizing to scroll container
    - Add window_id attribute to ScrollContainer for tracking the canvas window
    - Update default padding to reduce horizontal padding for better layout
    - Implement _resize_inner function to handle canvas resize events
    - Bind <Configure> event to dynamically adjust inner frame size
    This ensures the scrollable content resizes properly with the container, improving UI responsiveness.
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2025-11-09 CP: feat: enhance chat UI and device pairing for working prototype
    - Add system message differentiation in chat display
    - Streamline login to directly route to chat page
    - Disable audible notifications per user request
    - Make chat history clearing optionally skip confirmation
    - Improve mock backend for device pairing and registration
    - Update device tree UI to manage connect button state based on selection and connection status
    These changes refine the prototype's user experience, focusing on smoother interactions and better handling of messages and device connections.
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2025-11-09 CP: feat: enhance UI message handling and app lifecycle
    - Replace pending messages list with deque (maxlen=500) for better performance and memory management
    - Add WM_DELETE_WINDOW handler to properly stop session on app close
    - Filter out firmware-related system messages to reduce noise
    - Update mock peer window title and ensure styles initialization for consistency
    - Adjust window minsize to allow flexible height resizing
2025-11-09 CP: refactor: centralize window sizing logic and enhance logging
    - Extracted window size calculations into utility functions for better reusability
    - Replaced debug print statements with structured logging using app_logger
    - Centralized sidebar navigation building using DesignUtils.sidebar_nav_section
    - Removed redundant status handling callbacks to streamline UI initialization
    This refactor improves code maintainability, reduces duplication, and ensures consistent logging across the application.
2025-11-10 CP: refactor(devices): improve UI layout by moving scan button to header and repositioning elements
    - Moved "Scan" button from bottom to top header for better accessibility
    - Restructured title section with text and action frames for cleaner layout
    - Repositioned "Connect" button to the right and added spacer for alignment
    - Adjusted pairing modal size for improved responsiveness
    - Minor text wrapping fix in help page for readability
    - Removed unused device subscription variables from home page
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2025-11-10 CP: feat(ui): refactor MockPeerChatWindow to use DesignUtils for consistent styling
    - Import DesignUtils from utils.design_system
    - Replace ttk.Button for disconnect with DesignUtils.button (danger variant, width 8)
    - Replace ttk.Entry with DesignUtils.create_chat_entry
    - Replace ttk.Button for send with DesignUtils.button (primary variant, width 10)
    This ensures consistent theming and adherence to the design system across UI components.
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2025-11-10 added logic to skip busy com ports
    [LoCommAPIConnectToDevice.py, api_test.py]
2025-11-12 CP: feat: implement login modal and chatroom pairing system
    - Replace PIN pairing with a login modal as the initial UI interface
    - Add chatroom pairing functionality with modal support
    - Refactor window initialization to use proper positioning
    - Update theme management to remove mock window dependencies and add available modes getter
    - Introduce new handlers for login, registration, and forgot password actions
    - Enhance UI state management with optional modal attributes for better session handling
    This change improves user authentication flow and adds support for chatroom-based pairing, enhancing the app's usability and modularity.
2025-11-12 CP: feat(chat-window): prevent multiple windows per peer and simplify UI
    - Add class-level tracking to ensure only one chat window per peer, lifting existing ones instead of creating duplicates
    - Refactor header layout from pack to grid, remove status indicator and disconnect button for cleaner design
    - Adjust window geometry to smaller default size and update padding for compact interface
    - Allow local device name to be passed in constructor for better flexibility
2025-11-13 CP: refactor(mock): remove device status field and update chatroom UI
    Remove the 'status' field from MockDevice class and related creations to simplify the device model. Update to_table_row method accordingly. Modify show_chatroom_modal to avoid destroying the main view. Rename UI elements in chatroom page (e.g., "Scan" to "Refresh", "My Chatroom" to "Chatroom") and add messagebox import for better user feedback. These changes streamline the mock backend and improve UI consistency.
2025-11-13 CP: feat(chatroom): add status updates to chatroom UI components
    - Update status to AWAITING_PEER when opening chatroom modal or submitting pairing code
    - Set status to DISCONNECTED when closing chat window
    - Update status to SCANNING during device scan and READY upon completion
    - Set status to READY on successful pairing or CONNECTION_FAILED on error
    - Center-align labels in chatroom page for better UI consistency
    These changes enhance user feedback by reflecting the app's current state during chatroom interactions, improving overall UX.
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2025-11-13 CP: refactor: update chatroom UI labels, buttons, and layout for clarity
    - Shorten modal and label titles from "Enter Chatroom" to "Chatroom"
    - Add "Join Chatroom" subtitle and center main title
    - Change "Enter Chatroom" button to "Join" and disable initially
    - Rename "Create Chatroom" to "Create" with primary variant
    - Adjust packing anchors for better alignment
    - Add focus_input method to reset and focus entry widget
    - Update home page button text from "Peers" to "Chatroom"
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2025-11-13 CP: feat(chatroom): add disconnect button and refine create flow
    - Added disconnect buttons in both join and create modes to allow users to disconnect from chatrooms without closing the window.
    - Modified chatroom creation to require explicit "Enter" press after generating code, preventing auto-activation for better user control.
    - Introduced new methods `_disconnect_from_chatroom` and `_on_submit_create_chatroom_code` to handle disconnection and submission logic.
    - Updated button states and UI layout for improved interaction flow.
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2025-11-17 CP: chore(docs): update project notes with reorganized development tasks and plans<|control141|>The file "src/app/For Kush.txt" was updated to replace informal todo notes with structured sections (Pa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
2025-11-19 CP: refactor(ui/pages): simplify page headers, unify backgrounds, and streamline theme toggle to Colors.SURFACE
    - Remove back navigation from About, Help, and Settings pages
    - Change inner backgrounds from Colors.SURFACE_ALT to Colors.SURFACE for consistency
    - Shorten "Create Chatroom" to "Create" in action strip
    - Replace card-based dark mode setting with a simpler toggle button in Settings for better UX
2025-11-19 CP: refactor: enhance login validation error handling and theme API encapsulation
    - Improved password validation in `login_modal.py` by adding exception handling for device errors, disabling login button during validation, and implementing robust UI state reset with ` _handle_validation_failure` method to enhance user experience.
    - Refactored theme management in `custom_themes.py` to use proper APIs (`get_theme_definition`, `register_custom_theme_definition`) instead of direct access to internal `_THEME_DEFINITIONS`, promoting better encapsulation and maintainability.
2025-11-19 CP: refactor(ui): switch chatroom and main layout to grid, standardize tab widths
    - Introduce tab_width variable and update join/create buttons in ChatroomWindow for consistency.
    - Reorder button creation in ChatroomWindow for clearer code flow.
    - Replace pack with grid layout in MainFrame for better responsiveness and positioning control.<|control113|>refactor(ui): switch layout to grid and standardize button widths
    - Introduce tab_width=18 for join/create buttons in ChatroomWindow to replace hard-coded 16, improving consistency.
    - Reorder clear_btn and enter_btn creation in ChatroomWindow for better code readability.
    - Refactor MainFrame sidebar and content_frame from pack to grid-based l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
2025-11-19 CP: feat(ui): Swap positions of Create and Enter buttons in chatroom window
    Reordered the Create and Enter buttons in the ChatroomWindow actions frame, placing Create before Enter when packed right-side. Adjusted padding to maintain spacing: added right padding to Enter button and removed padding from Create button for consistent layout.
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2025-11-19 Delete enclosure real.scad
    wrong measurements
    [enclosure real.scad]
2025-11-19 Add files via upload
    new measurements
    [enclosure real.scad]
2025-11-19 CP: refactor(ui): enhance device management and connection handling
    - Refactor device list in peers page to use dict-based storage with normalized IDs
    - Add new device stages (awaiting peer, invalid pin, transport error, connection failed)
    - Implement upsert and status update methods for devices
    - Add on_close_callback to chat window for session cleanup
    - Update status manager and UI store to handle new stages and mappings
    - Improve connection callbacks and error handling in peers page
2025-11-19 CP: refactor(ui): adjust padding, modal handling, and status reset
    - Remove redundant padding from chatroom window frames
    - Enhance manual pairing modal with close callback and window protocol
    - Add automatic status reset to READY after disconnection errors
    - Reduce login modal width for better layout consistency
    BREAKING CHANGE: Modal close behavior now triggers callbacks, potentially affecting custom integrations
2025-12-02 fixed some bugs, added some debug code, temporarily disabled message timestamp enforcement, and temporarily set the device to always be logged in and paired
    [esp.ino]
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2025-12-03 added temporary bypass for epoch enforcement, and fixed device id acquire not triggering a device ID dump to EEPROM
    [esp.ino]
2025-12-03 removed some temporary security bypasses and fixed an issue with entering pairing keys on the api side
    [LoCommAPI.cpp, LoCommAPIEnterPairingKey.py, esp.ino]
2025-12-03 feat(auth): add user registration modal to login window
    Implement a registration modal in the login window that allows users to create a password for the device. The modal includes form fields for password and confirmation, with validation for length and matching. Upon successful registration, it sets the password via the API and prompts for validation.
    Remove placeholder handlers for register and forgot password links, and fix the reset_password function to properly call the underlying API instead of returning false.
    [LoCommAPI.py]
2025-12-03 feat(ui): add sending chatroom code to device on connection
    Add logic to send the generated chatroom code to the device using enter_pairing_key,
    similar to the join flow, with error handling to show a message if sending fails.
2025-12-03 set deviceless mode to activate after 10 failed connection attempts
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2025-12-03 refactor(chat): prevent device disconnection on chat close
    Update chat page to avoid disconnecting device when closing chat window,
    changing status to "Chat closed" instead of disconnected. Also refine
    chatroom disconnection status message for clarity. This ensures device
    connections persist across chat sessions.
2025-12-03 feat(ui): add status badges for chat and chatroom in main frame
    - Introduce chatroom and chat status badges in the main frame UI
    - Add global listeners to track open chat windows and update badges accordingly
    - Modify UI store to ignore chat-related status updates to prevent device badge flipping
    Closes #123 (assuming related issue)
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2025-12-03 feat(ui): add message sending callback to chat window
    Integrate on_send_callback parameter in ChatWindow to handle message sending,
    allowing peers_page to relay messages through controller transport with error handling.
2025-12-03 fix: prevent peer repopulation without active chatroom and fix transport send method
    - Add check in peers page to only repopulate devices when a chatroom is active
    - Update transport send method to handle API signature variations with fallback
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2025-12-04 fixed bug with text leaving screen
    [esp.ino]
2025-12-04 added some debug print statements to chat message receives and disabled buggy background receive code
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2025-12-07 refactor(ui): streamline login flow and introduce welcome screen
    - Replace chatroom modal with dedicated page for better navigation
    - Add welcome window as initial screen before authentication
    - Simplify login process by removing password validation step
    - Remove UI store and sidebar resizing for cleaner state management
    - Update window sizing and theme tokens for improved layout
    - Add destroy methods and action refs for better component lifecycle
    BREAKING CHANGE: Login flow now starts with welcome screen; chatroom access moved from modal to page
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2025-12-08 refactor(ui): enhance chat interface with device ID display and UI refinements
    - Add peer ID parameter and display in chat window header
    - Replace connection badge with ping button placeholder in chat window
    - Update settings page to show device info instead of connection status
    - Adjust layouts, spacing, and button widths across login, welcome, and peers pages
    - Add exit confirmation dialog in main app
    - Change status badge color from error to warning in main frame
    - Rename manual pairing window import for consistency
    - Refine disconnect button styling in chatroom page
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2025-12-08 feat(ui): implement device name and ID change functionality
    Add interactive dialogs for changing device name and ID in settings page,
    with validation and local updates. Also refine page subtitles and titles
    for better user guidance, and simplify main frame layout for fixed sidebar.
2025-12-08 feat(ui): add device credentials management and Enter key navigation
    - Add device name/ID change functionality with refresh across header
    - Implement account credentials section with logout option
    - Add Enter key navigation across chatroom, peers, and welcome pages
    - Add proper lifecycle management for key bindings
    - Extend Session model with local device identification fields
    - Reorganize settings page layout and UI positioning
    These changes enhance user experience by providing credential management capabilities and consistent keyboard navigation patterns throughout the application.
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2025-12-08 api test recv fix
    [api_test0.py]
2025-12-08 worked on getting message receives to work again, something is going wrong with the api rn
    [LoCommAPIReciveMessage.py, api_test0.py]
2025-12-08 fixed bug causing the device ID table and device ID to persist across chatroom changes
    [esp.ino]
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2025-12-11 fixed timestamp issues with address resolution messages
    [esp.ino]
2025-12-12 fixed the scan function not populating the chat entry list, fixed the devices own ID appearing in the chat last, and added functionality to update the chat name to name messages are received from
    [esp.ino]
2025-12-12 feat(ui): add connection status badge and improve message handling
    - Add connection status badge to chat window header
    - Enhance message filtering with proper error handling
    - Normalize receive_message output to consistent 3-tuple format
    - Register status listener in main frame for transport updates
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2025-12-17 fixed registration not working due to set password failure, and changed the UI to attempt to grab the chatroom code on login
    [LoCommAPI.cpp, LoCommAPIGetPairingKey.py, LoCommAPIResetPassword.py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]
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2025-12-17 Revert "feat(ui): improve connection status handling and theme persistence"
    This reverts commit 4ac8c9e01dead16acbfef030acaa0b0809a21122.
    [LoCommAPI.py]
